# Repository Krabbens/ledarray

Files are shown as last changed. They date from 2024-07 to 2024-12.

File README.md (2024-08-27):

# Kolorowy wyświetlacz widmowy

## Spis Treści

- [Aplikacja](#flutter)
- [ESP PlatformIO](#esp-platformio)
- [PCB](#pcb)
- [Blender](#blender)
- [Przetwarzanie wstępne](#przetwarzanie-wstępne)

## Aplikacja do kontroli

1. Zainstaluj Flutter:

    - Pobierz Flutter SDK z https://flutter.dev/docs/get-started/install
    - Dodaj Flutter bin do PATH

2. Sprawdź instalację:

    ```bash
    flutter doctor
    ```

3. Uruchom projekt:

    ```bash
    cd /ścieżka/do/projektu
    flutter run
    ```

## ESP PlatformIO

1. Zainstaluj PlatformIO:

    - Pobierz PlatformIO IDE z https://platformio.org/install/ide?install=vscode

2. Skopiuj pliki z folderu esp/core_lib do odpowiadających folderów bibliotek espressif32 w domyślnej lokalizacji platformio

3. Uruchom projekt:

    - Otwórz PlatformIO IDE, załaduj projekt, użyj opcji "Build" i "Upload"

## PCB

1. Zainstaluj KiCad:

    - Pobierz KiCad z https://kicad.org/download/

2. Otwórz projekt:

    - Załaduj istniejący plik PCB w KiCad

## Blender

1. Zainstaluj Blender:

    - Pobierz Blender z https://www.blender.org/download/

2. Otwórz projekt:

    - Plik `cude.blend` jest głównym plikiem do renderowania animacji.
    - Plik `simul.blend` służy do symulacji animacji.

## Przetwarzanie wstępne

Zestaw skryptów służący do przetwarzania danych z blendera na format rozumiany przez program kontrolujący diody LED.

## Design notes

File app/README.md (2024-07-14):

# conn_app

A new Flutter project.

## Getting Started

This project is a starting point for a Flutter application.

A few resources to get you started if this is your first Flutter project:

- [Lab: Write your first Flutter app](https://docs.flutter.dev/get-started/codelab)
- [Cookbook: Useful Flutter samples](https://docs.flutter.dev/cookbook)

For help getting started with Flutter development, view the
[online documentation](https://docs.flutter.dev/), which offers tutorials,
samples, guidance on mobile development, and a full API reference.

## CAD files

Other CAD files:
3d/dysk v3.f3d
3d/kat 2 v1.f3d
3d/podstawa v2.f3d
3d/silnik góra v2.f3d
3d/silnik góra v3.f3d
3d/silnik v1 v2.f3d
3d/silnik v1 v3.f3d
3d/stopka trzymacza v2.f3d
3d/stopka trzymacza v3.f3d
3d/trzymacz v1.f3d
blender/atom.blend
blender/cube.blend

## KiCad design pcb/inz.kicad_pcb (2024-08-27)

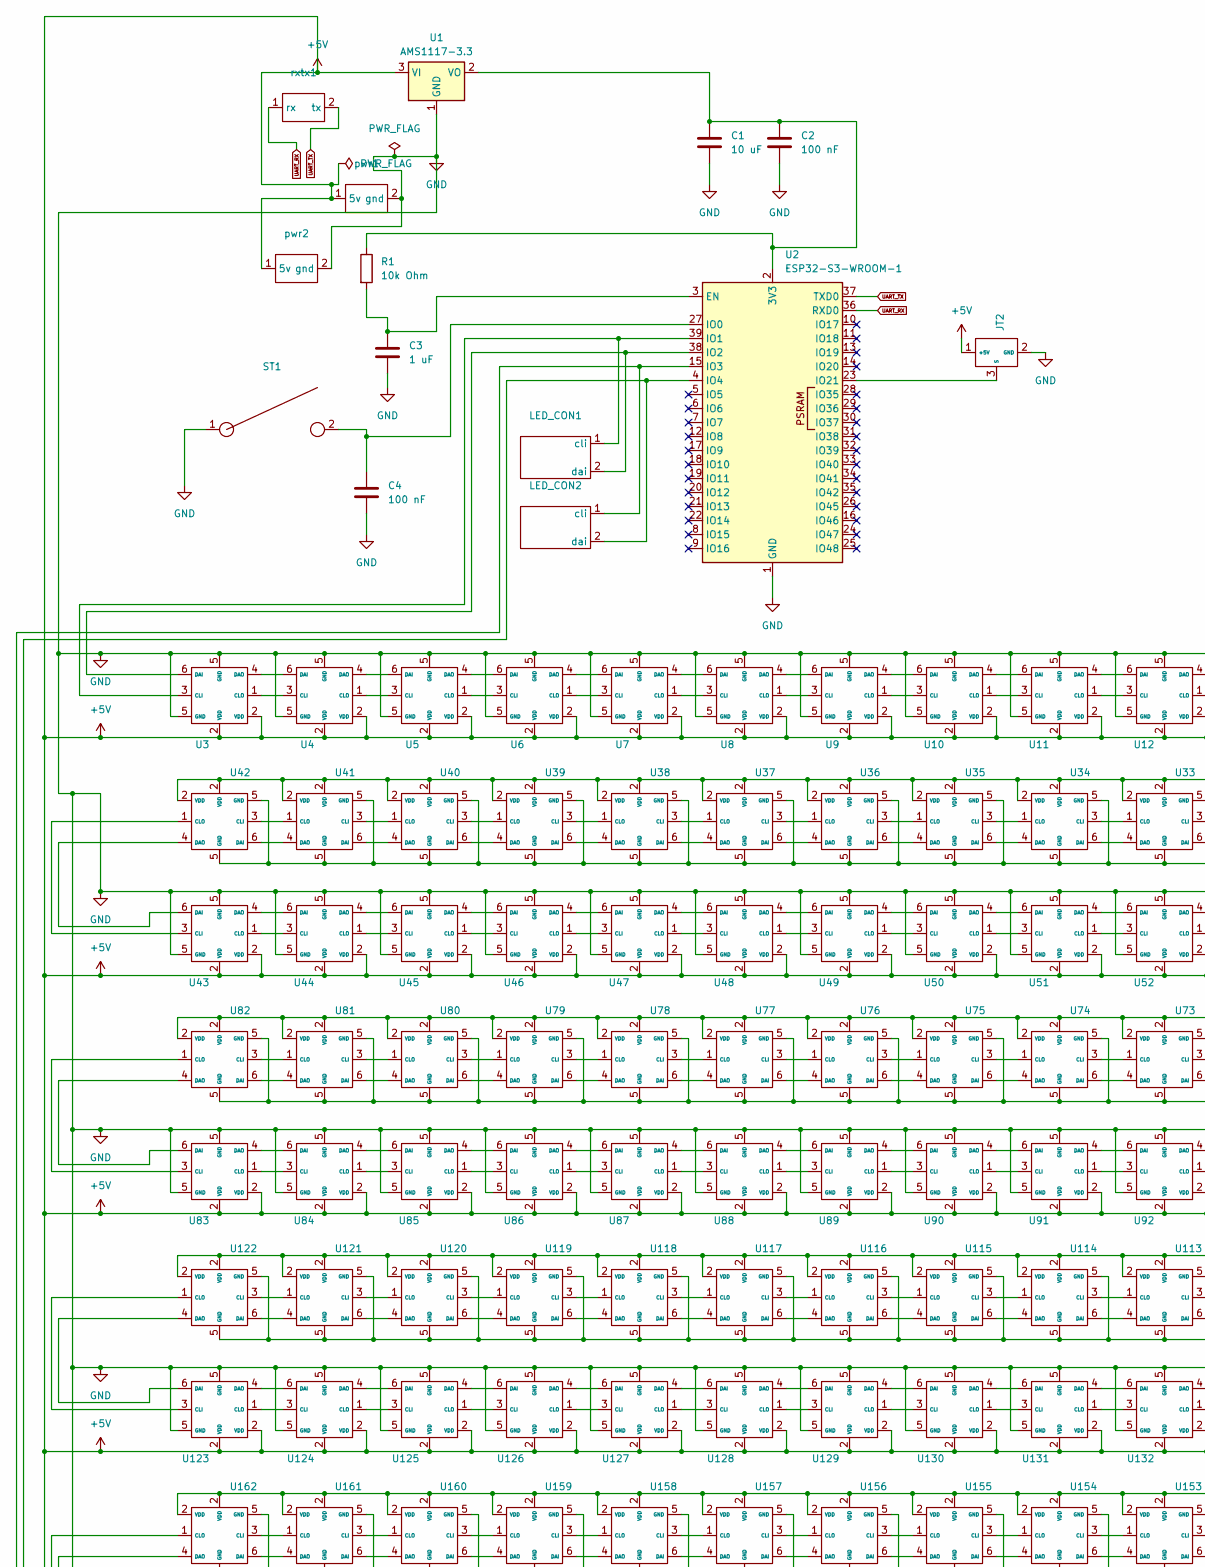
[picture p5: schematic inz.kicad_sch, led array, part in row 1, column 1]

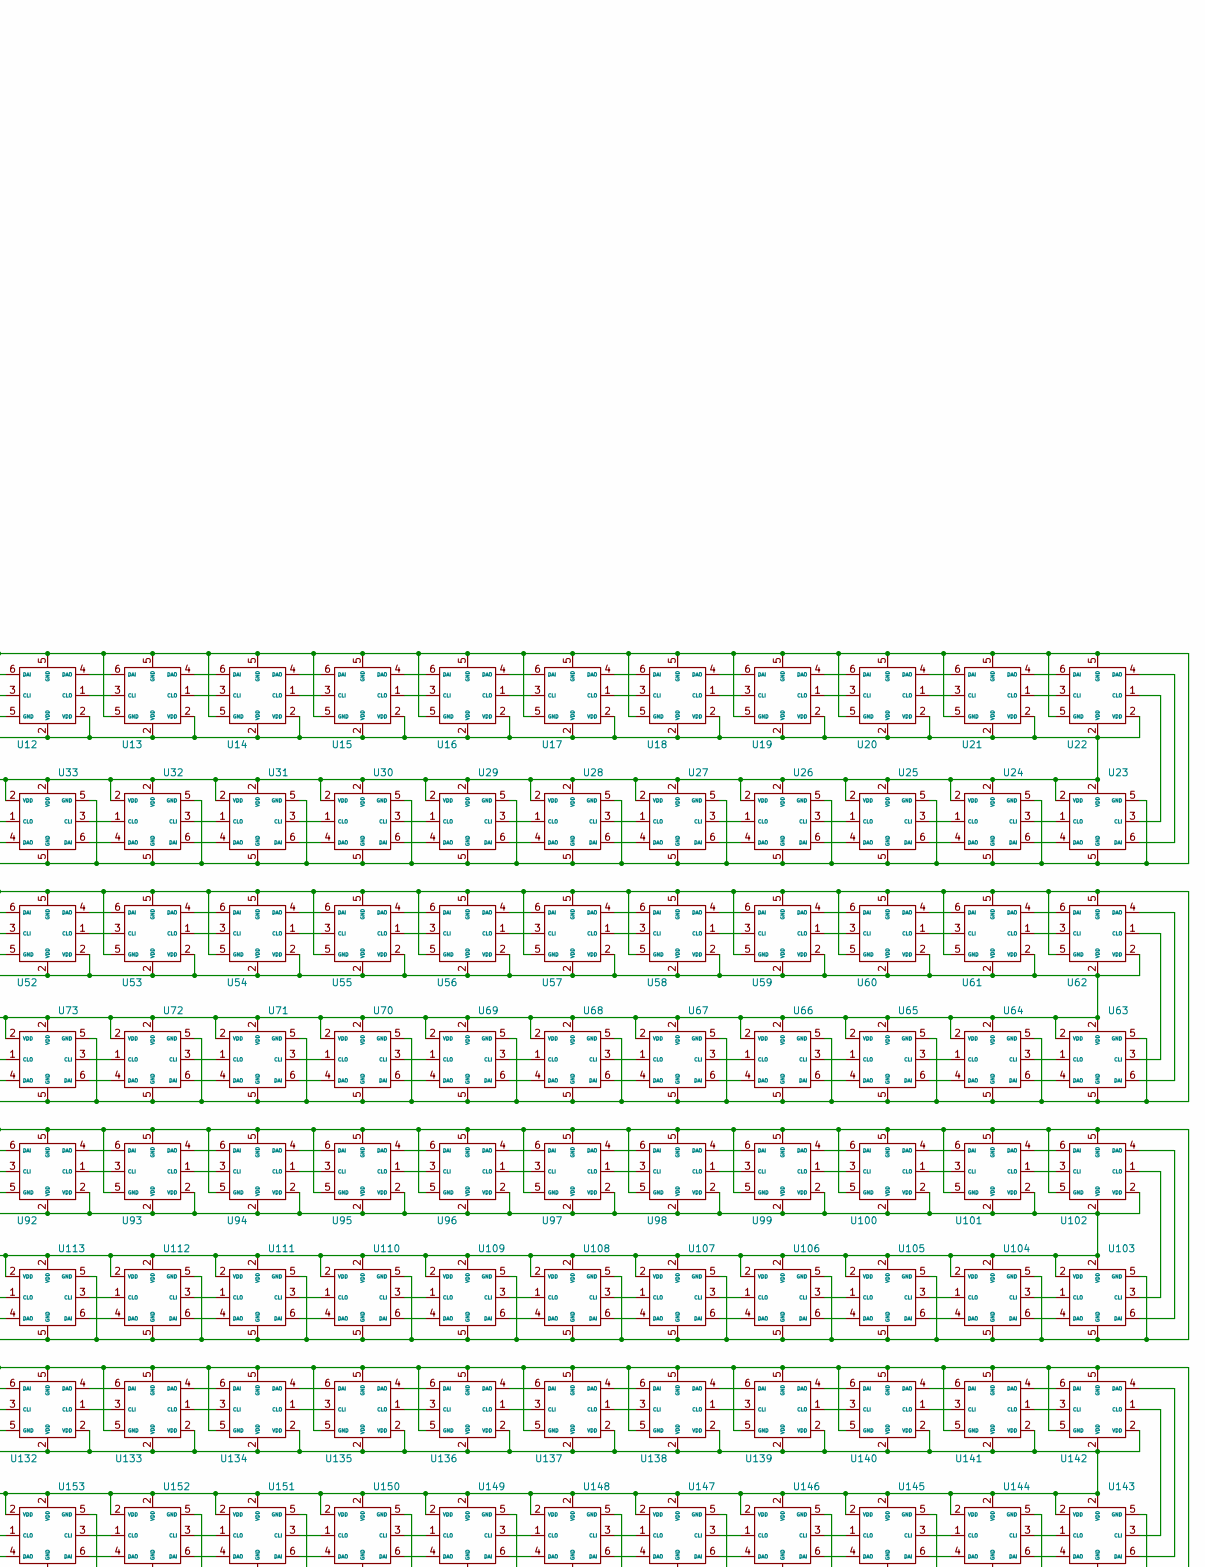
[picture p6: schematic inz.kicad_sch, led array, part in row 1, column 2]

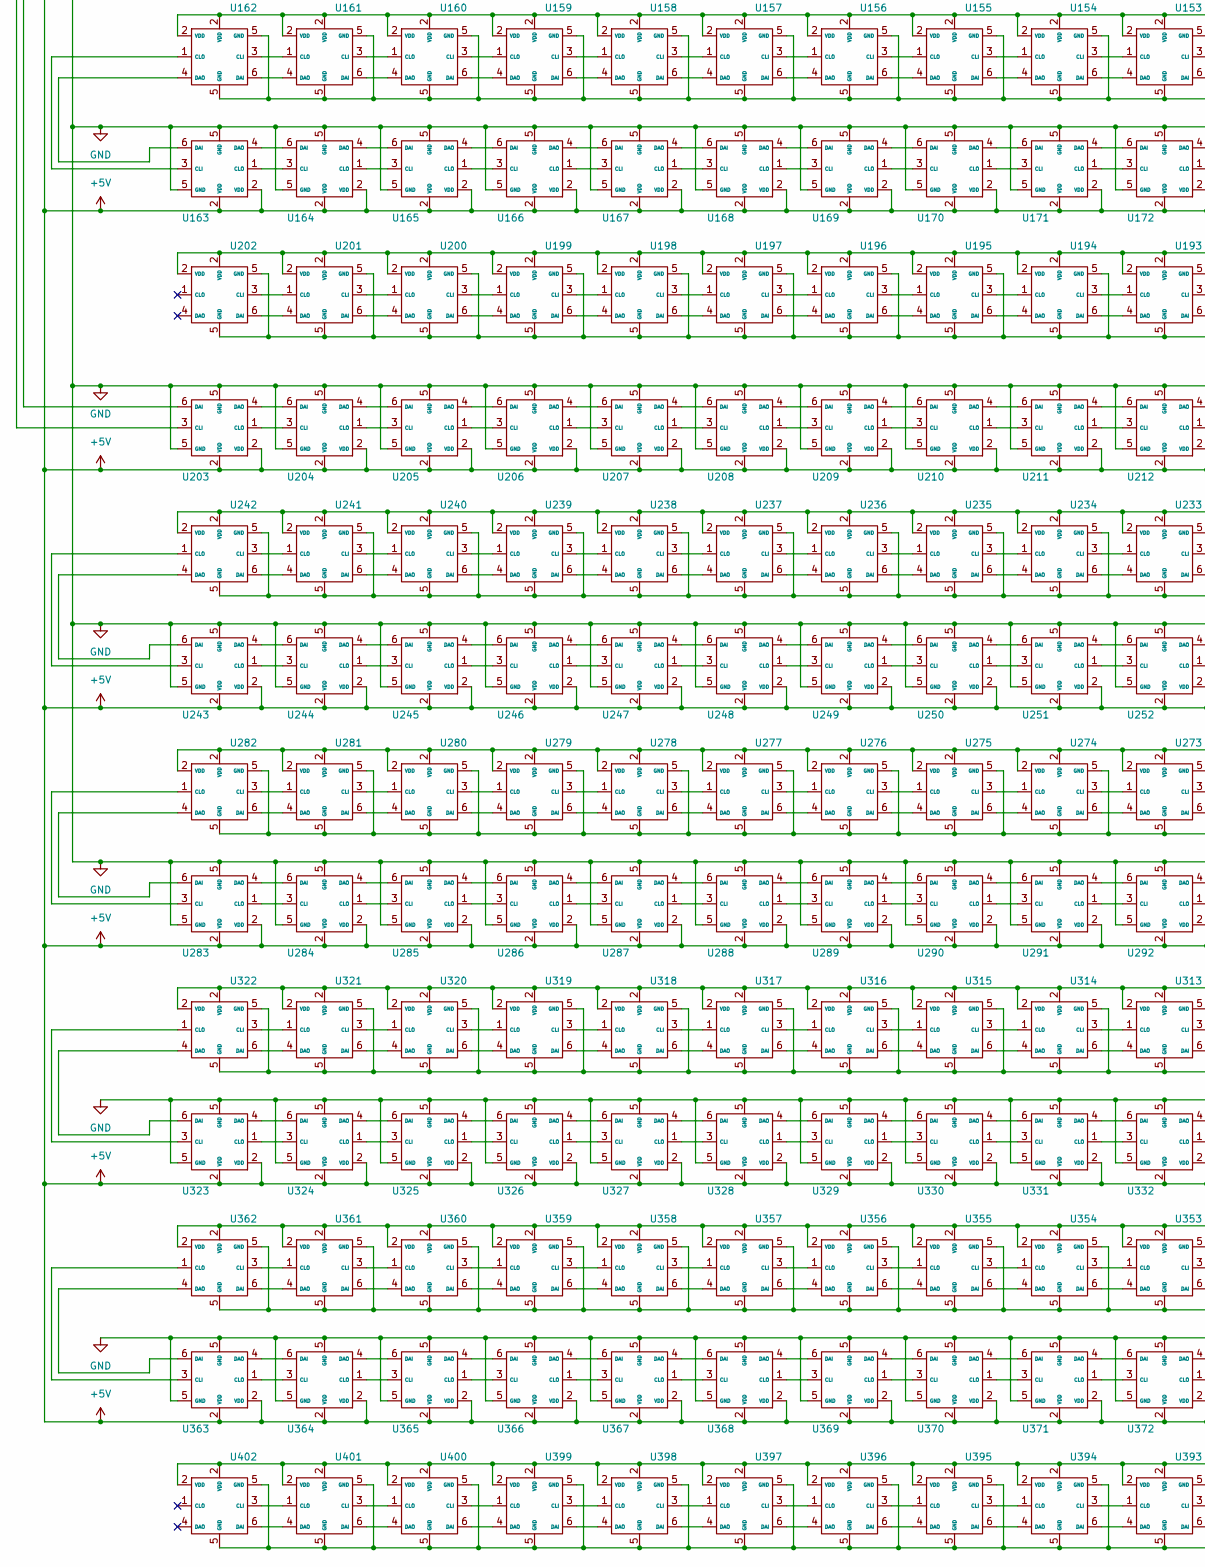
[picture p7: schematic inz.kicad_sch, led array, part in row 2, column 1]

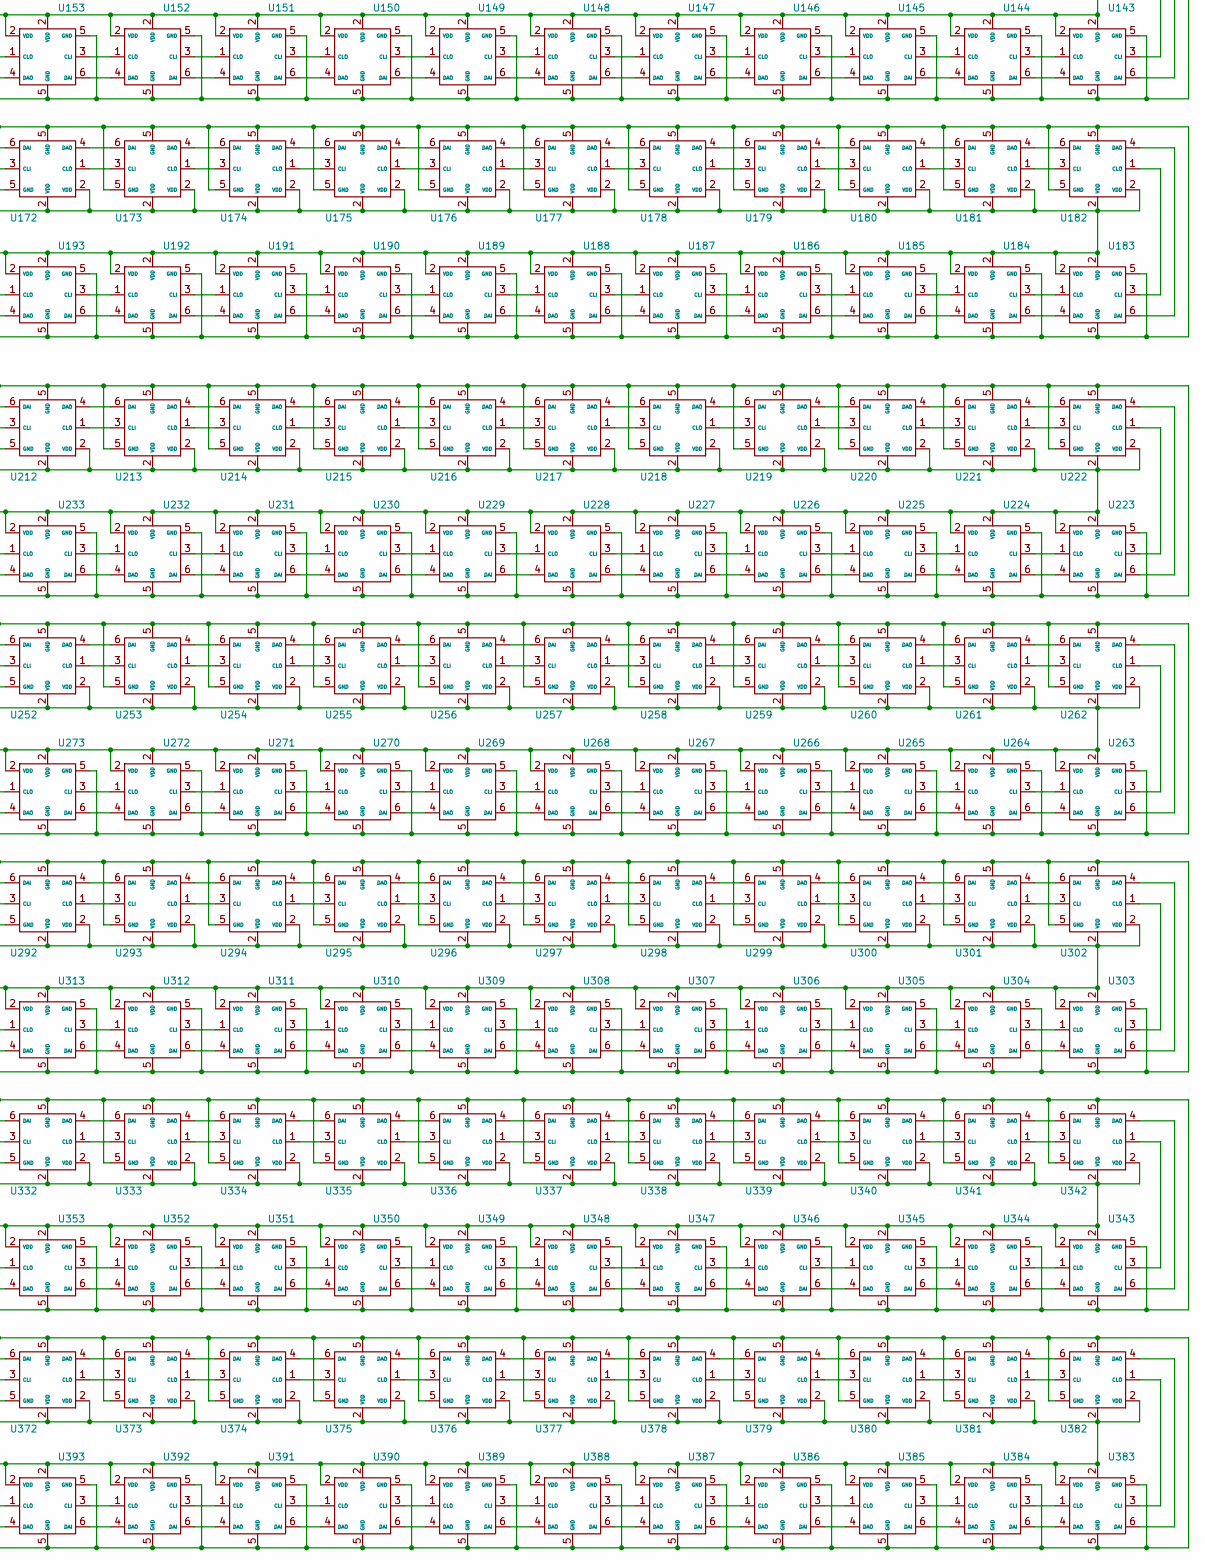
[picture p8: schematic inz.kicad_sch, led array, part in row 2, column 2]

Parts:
C1: 10 uF; C_0603_1608Metric
C2, C4: 100 nF; C_0402_1005Metric
C3: 1 uF; C_0402_1005Metric
JT2: hall JT
LED_CON1, LED_CON2: led_con
R1: 10k Ohm; R_0402_1005Metric
ST1: ST-1185S
U1: AMS1117-3.3; SOT-223-3_TabPin2
U2: ESP32-S3-WROOM-1
U3, U4, U5, U6, U7, U8, U9, U10, U11, U12, U13, U14, U15, U16, U17, U18, U19, U20, U21, U22, U23, U24, U25, U26, U27, U28, U29, U30, U31, U32, U33, U34, U35, U36, U37, U38, U39, U40, U41, U42, U43, U44, U45, U46, U47, U48, U49, U50, U51, U52, U53, U54, U55, U56, U57, U58, U59, U60, U61, U62, U63, U64, U65, U66, U67, U68, U69, U70, U71, U72, U73, U74, U75, U76, U77, U78, U79, U80, U81, U82, U83, U84, U85, U86, U87, U88, U89, U90, U91, U92, U93, U94, U95, U96, U97, U98, U99, U100, U101, U102, U103, U104, U105, U106, U107, U108, U109, U110, U111, U112, U113, U114, U115, U116, U117, U118, U119, U120, U121, U122, U123, U124, U125, U126, U127, U128, U129, U130, U131, U132, U133, U134, U135, U136, U137, U138, U139, U140, U141, U142, U143, U144, U145, U146, U147, U148, U149, U150, U151, U152, U153, U154, U155, U156, U157, U158, U159, U160, U161, U162, U163, U164, U165, U166, U167, U168, U169, U170, U171, U172, U173, U174, U175, U176, U177, U178, U179, U180, U181, U182, U183, U184, U185, U186, U187, U188, U189, U190, U191, U192, U193, U194, U195, U196, U197, U198, U199, U200, U201, U202, U203, U204, U205, U206, U207, U208, U209, U210, U211, U212, U213, U214, U215, U216, U217, U218, U219, U220, U221, U222, U223, U224, U225, U226, U227, U228, U229, U230, U231, U232, U233, U234, U235, U236, U237, U238, U239, U240, U241, U242, U243, U244, U245, U246, U247, U248, U249, U250, U251, U252, U253, U254, U255, U256, U257, U258, U259, U260, U261, U262, U263, U264, U265, U266, U267, U268, U269, U270, U271, U272, U273, U274, U275, U276, U277, U278, U279, U280, U281, U282, U283, U284, U285, U286, U287, U288, U289, U290, U291, U292, U293, U294, U295, U296, U297, U298, U299, U300, U301, U302, U303, U304, U305, U306, U307, U308, U309, U310, U311, U312, U313, U314, U315, U316, U317, U318, U319, U320, U321, U322, U323, U324, U325, U326, U327, U328, U329, U330, U331, U332, U333, U334, U335, U336, U337, U338, U339, U340, U341, U342, U343, U344, U345, U346, U347, U348, U349, U350, U351, U352, U353, U354, U355, U356, U357, U358, U359, U360, U361, U362, U363, U364, U365, U366, U367, U368, U369, U370, U371, U372, U373, U374, U375, U376, U377, U378, U379, U380, U381, U382, U383, U384, U385, U386, U387, U388, U389, U390, U391, U392, U393, U394, U395, U396, U397, U398, U399, U400, U401, U402: APA102-2020-6A
pwr1, pwr2: 5vgnd
rxtx1: rxtx

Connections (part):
+5V: JT2.1 (+5V), U1.3 (VI), U3.2 (VDD), U4.2 (VDD), U5.2 (VDD), U6.2 (VDD), U7.2 (VDD), U8.2 (VDD), U9.2 (VDD), U10.2 (VDD), U11.2 (VDD), U12.2 (VDD), U13.2 (VDD), U14.2 (VDD), U15.2 (VDD), U16.2 (VDD), U17.2 (VDD), U18.2 (VDD), U19.2 (VDD), U20.2 (VDD), U21.2 (VDD), U22.2 (VDD), U23.2 (VDD), U24.2 (VDD), U25.2 (VDD), U26.2 (VDD), U27.2 (VDD), U28.2 (VDD), U29.2 (VDD), U30.2 (VDD), U31.2 (VDD), U32.2 (VDD), U33.2 (VDD), U34.2 (VDD), U35.2 (VDD), U36.2 (VDD), U37.2 (VDD), U38.2 (VDD), U39.2 (VDD), U40.2 (VDD), U41.2 (VDD), U42.2 (VDD), U43.2 (VDD), U44.2 (VDD), U45.2 (VDD), U46.2 (VDD), U47.2 (VDD), U48.2 (VDD), U49.2 (VDD), U50.2 (VDD), U51.2 (VDD), U52.2 (VDD), U53.2 (VDD), U54.2 (VDD), U55.2 (VDD), U56.2 (VDD), U57.2 (VDD), U58.2 (VDD), U59.2 (VDD), U60.2 (VDD), U61.2 (VDD), U62.2 (VDD), U63.2 (VDD), U64.2 (VDD), U65.2 (VDD), U66.2 (VDD), U67.2 (VDD), U68.2 (VDD), U69.2 (VDD), U70.2 (VDD), U71.2 (VDD), U72.2 (VDD), U73.2 (VDD), U74.2 (VDD), U75.2 (VDD), U76.2 (VDD), U77.2 (VDD), U78.2 (VDD), U79.2 (VDD), U80.2 (VDD)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
GND: C1.2, C2.2, C3.2, C4.2, JT2.2 (GND), ST1.1, U1.1 (GND), U2.1 (GND), U2.40 (GND), U2.41 (GND), U3.5 (GND), U4.5 (GND), U5.5 (GND), U6.5 (GND), U7.5 (GND), U8.5 (GND), U9.5 (GND), U10.5 (GND), U11.5 (GND), U12.5 (GND), U13.5 (GND), U14.5 (GND), U15.5 (GND), U16.5 (GND), U17.5 (GND), U18.5 (GND), U19.5 (GND), U20.5 (GND), U21.5 (GND), U22.5 (GND), U23.5 (GND), U24.5 (GND), U25.5 (GND), U26.5 (GND), U27.5 (GND), U28.5 (GND), U29.5 (GND), U30.5 (GND), U31.5 (GND), U32.5 (GND), U33.5 (GND), U34.5 (GND), U35.5 (GND), U36.5 (GND), U37.5 (GND), U38.5 (GND), U39.5 (GND), U40.5 (GND), U41.5 (GND), U42.5 (GND), U43.5 (GND), U44.5 (GND), U45.5 (GND), U46.5 (GND), U47.5 (GND), U48.5 (GND), U49.5 (GND), U50.5 (GND), U51.5 (GND), U52.5 (GND), U53.5 (GND), U54.5 (GND), U55.5 (GND), U56.5 (GND), U57.5 (GND), U58.5 (GND), U59.5 (GND), U60.5 (GND), U61.5 (GND), U62.5 (GND), U63.5 (GND), U64.5 (GND), U65.5 (GND), U66.5 (GND), U67.5 (GND), U68.5 (GND), U69.5 (GND), U70.5 (GND), U71.5 (GND), U72.5 (GND)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
unnamed: JT2.3 (S), U2.23 (IO21)
unnamed: LED_CON1.1 (cli), U2.39 (IO1), U3.3 (CLI)
unnamed: LED_CON1.2 (dai), U2.38 (IO2), U3.6 (DAI)
unnamed: LED_CON2.1 (cli), U2.15 (IO3), U203.3 (CLI)
unnamed: LED_CON2.2 (dai), U2.4 (IO4), U203.6 (DAI)
unnamed: C1.1, C2.1, R1.1, U1.2 (VO), U2.2 (3V3)
unnamed: C3.1, R1.2, U2.3 (EN)
unnamed: C4.1, ST1.2, U2.27 (IO0)
unnamed: U3.1 (CLO), U4.3 (CLI)
unnamed: U3.4 (DAO), U4.6 (DAI)
unnamed: U4.1 (CLO), U5.3 (CLI)
unnamed: U4.4 (DAO), U5.6 (DAI)
unnamed: U5.1 (CLO), U6.3 (CLI)
unnamed: U5.4 (DAO), U6.6 (DAI)
unnamed: U6.1 (CLO), U7.3 (CLI)
unnamed: U6.4 (DAO), U7.6 (DAI)
unnamed: U7.1 (CLO), U8.3 (CLI)
unnamed: U7.4 (DAO), U8.6 (DAI)
unnamed: U8.1 (CLO), U9.3 (CLI)
unnamed: U8.4 (DAO), U9.6 (DAI)
unnamed: U9.1 (CLO), U10.3 (CLI)
unnamed: U10.1 (CLO), U11.3 (CLI)
unnamed: U9.4 (DAO), U10.6 (DAI)
unnamed: U10.4 (DAO), U11.6 (DAI)
unnamed: U11.1 (CLO), U12.3 (CLI)
unnamed: U11.4 (DAO), U12.6 (DAI)
unnamed: U12.1 (CLO), U13.3 (CLI)
unnamed: U12.4 (DAO), U13.6 (DAI)
unnamed: U13.1 (CLO), U14.3 (CLI)
unnamed: U13.4 (DAO), U14.6 (DAI)
unnamed: U14.1 (CLO), U15.3 (CLI)
unnamed: U14.4 (DAO), U15.6 (DAI)
unnamed: U15.1 (CLO), U16.3 (CLI)
unnamed: U15.4 (DAO), U16.6 (DAI)
unnamed: U16.1 (CLO), U17.3 (CLI)
unnamed: U16.4 (DAO), U17.6 (DAI)
unnamed: U17.1 (CLO), U18.3 (CLI)
unnamed: U17.4 (DAO), U18.6 (DAI)
unnamed: U18.1 (CLO), U19.3 (CLI)
unnamed: U18.4 (DAO), U19.6 (DAI)
unnamed: U19.1 (CLO), U20.3 (CLI)
unnamed: U19.4 (DAO), U20.6 (DAI)
unnamed: U20.1 (CLO), U21.3 (CLI)
unnamed: U20.4 (DAO), U21.6 (DAI)
unnamed: U21.1 (CLO), U22.3 (CLI)
unnamed: U21.4 (DAO), U22.6 (DAI)
unnamed: U22.1 (CLO), U23.3 (CLI)
unnamed: U22.4 (DAO), U23.6 (DAI)
unnamed: U23.1 (CLO), U24.3 (CLI)
unnamed: U23.4 (DAO), U24.6 (DAI)
unnamed: U24.1 (CLO), U25.3 (CLI)
unnamed: U24.4 (DAO), U25.6 (DAI)
unnamed: U25.1 (CLO), U26.3 (CLI)
unnamed: U25.4 (DAO), U26.6 (DAI)
unnamed: U26.1 (CLO), U27.3 (CLI)
unnamed: U26.4 (DAO), U27.6 (DAI)
unnamed: U27.1 (CLO), U28.3 (CLI)
unnamed: U27.4 (DAO), U28.6 (DAI)
unnamed: U28.1 (CLO), U29.3 (CLI)
unnamed: U28.4 (DAO), U29.6 (DAI)
unnamed: U29.1 (CLO), U30.3 (CLI)
unnamed: U29.4 (DAO), U30.6 (DAI)
unnamed: U30.1 (CLO), U31.3 (CLI)
unnamed: U30.4 (DAO), U31.6 (DAI)
unnamed: U31.1 (CLO), U32.3 (CLI)
unnamed: U31.4 (DAO), U32.6 (DAI)
unnamed: U32.1 (CLO), U33.3 (CLI)
unnamed: U32.4 (DAO), U33.6 (DAI)
unnamed: U33.1 (CLO), U34.3 (CLI)
unnamed: U33.4 (DAO), U34.6 (DAI)
unnamed: U34.1 (CLO), U35.3 (CLI)
unnamed: U34.4 (DAO), U35.6 (DAI)
unnamed: U35.1 (CLO), U36.3 (CLI)
unnamed: U35.4 (DAO), U36.6 (DAI)
unnamed: U36.1 (CLO), U37.3 (CLI)
unnamed: U36.4 (DAO), U37.6 (DAI)
unnamed: U37.1 (CLO), U38.3 (CLI)
unnamed: U37.4 (DAO), U38.6 (DAI)
unnamed: U38.1 (CLO), U39.3 (CLI)
unnamed: U38.4 (DAO), U39.6 (DAI)
unnamed: U39.1 (CLO), U40.3 (CLI)
unnamed: U39.4 (DAO), U40.6 (DAI)
unnamed: U40.1 (CLO), U41.3 (CLI)
unnamed: U40.4 (DAO), U41.6 (DAI)
unnamed: U41.1 (CLO), U42.3 (CLI)
unnamed: U41.4 (DAO), U42.6 (DAI)
unnamed: U42.1 (CLO), U43.3 (CLI)
unnamed: U42.4 (DAO), U43.6 (DAI)
unnamed: U43.1 (CLO), U44.3 (CLI)
unnamed: U43.4 (DAO), U44.6 (DAI)
unnamed: U44.1 (CLO), U45.3 (CLI)
unnamed: U44.4 (DAO), U45.6 (DAI)
unnamed: U45.1 (CLO), U46.3 (CLI)
unnamed: U45.4 (DAO), U46.6 (DAI)
unnamed: U46.1 (CLO), U47.3 (CLI)
unnamed: U46.4 (DAO), U47.6 (DAI)
unnamed: U47.1 (CLO), U48.3 (CLI)
unnamed: U47.4 (DAO), U48.6 (DAI)
unnamed: U48.1 (CLO), U49.3 (CLI)
unnamed: U48.4 (DAO), U49.6 (DAI)
unnamed: U49.1 (CLO), U50.3 (CLI)
unnamed: U49.4 (DAO), U50.6 (DAI)
unnamed: U50.1 (CLO), U51.3 (CLI)
unnamed: U50.4 (DAO), U51.6 (DAI)
unnamed: U51.1 (CLO), U52.3 (CLI)
unnamed: U51.4 (DAO), U52.6 (DAI)
unnamed: U52.1 (CLO), U53.3 (CLI)
unnamed: U52.4 (DAO), U53.6 (DAI)
unnamed: U53.1 (CLO), U54.3 (CLI)
unnamed: U53.4 (DAO), U54.6 (DAI)
unnamed: U54.1 (CLO), U55.3 (CLI)
unnamed: U54.4 (DAO), U55.6 (DAI)
unnamed: U55.1 (CLO), U56.3 (CLI)
unnamed: U55.4 (DAO), U56.6 (DAI)
unnamed: U56.1 (CLO), U57.3 (CLI)
unnamed: U56.4 (DAO), U57.6 (DAI)
unnamed: U57.1 (CLO), U58.3 (CLI)
unnamed: U57.4 (DAO), U58.6 (DAI)
unnamed: U58.1 (CLO), U59.3 (CLI)
unnamed: U58.4 (DAO), U59.6 (DAI)
unnamed: U59.1 (CLO), U60.3 (CLI)
unnamed: U59.4 (DAO), U60.6 (DAI)
unnamed: U60.1 (CLO), U61.3 (CLI)
unnamed: U60.4 (DAO), U61.6 (DAI)
unnamed: U61.1 (CLO), U62.3 (CLI)
unnamed: U61.4 (DAO), U62.6 (DAI)
unnamed: U62.1 (CLO), U63.3 (CLI)
unnamed: U62.4 (DAO), U63.6 (DAI)
unnamed: U63.1 (CLO), U64.3 (CLI)
unnamed: U63.4 (DAO), U64.6 (DAI)
unnamed: U64.1 (CLO), U65.3 (CLI)
unnamed: U64.4 (DAO), U65.6 (DAI)
unnamed: U65.1 (CLO), U66.3 (CLI)
unnamed: U65.4 (DAO), U66.6 (DAI)
unnamed: U66.1 (CLO), U67.3 (CLI)
unnamed: U66.4 (DAO), U67.6 (DAI)
unnamed: U67.1 (CLO), U68.3 (CLI)
unnamed: U67.4 (DAO), U68.6 (DAI)
unnamed: U68.1 (CLO), U69.3 (CLI)
unnamed: U68.4 (DAO), U69.6 (DAI)
unnamed: U69.1 (CLO), U70.3 (CLI)
unnamed: U69.4 (DAO), U70.6 (DAI)
unnamed: U70.1 (CLO), U71.3 (CLI)
unnamed: U70.4 (DAO), U71.6 (DAI)
unnamed: U71.1 (CLO), U72.3 (CLI)
unnamed: U71.4 (DAO), U72.6 (DAI)
unnamed: U72.1 (CLO), U73.3 (CLI)
unnamed: U72.4 (DAO), U73.6 (DAI)
unnamed: U73.1 (CLO), U74.3 (CLI)
unnamed: U73.4 (DAO), U74.6 (DAI)
unnamed: U74.1 (CLO), U75.3 (CLI)
unnamed: U74.4 (DAO), U75.6 (DAI)
unnamed: U75.1 (CLO), U76.3 (CLI)
unnamed: U75.4 (DAO), U76.6 (DAI)
unnamed: U76.1 (CLO), U77.3 (CLI)
unnamed: U76.4 (DAO), U77.6 (DAI)
unnamed: U77.1 (CLO), U78.3 (CLI)
unnamed: U77.4 (DAO), U78.6 (DAI)
unnamed: U78.1 (CLO), U79.3 (CLI)
unnamed: U78.4 (DAO), U79.6 (DAI)
unnamed: U79.1 (CLO), U80.3 (CLI)
unnamed: U79.4 (DAO), U80.6 (DAI)
unnamed: U80.1 (CLO), U81.3 (CLI)
unnamed: U80.4 (DAO), U81.6 (DAI)
unnamed: U81.1 (CLO), U82.3 (CLI)
unnamed: U81.4 (DAO), U82.6 (DAI)
unnamed: U82.1 (CLO), U83.3 (CLI)
unnamed: U82.4 (DAO), U83.6 (DAI)
unnamed: U83.1 (CLO), U84.3 (CLI)
unnamed: U83.4 (DAO), U84.6 (DAI)
unnamed: U84.1 (CLO), U85.3 (CLI)
unnamed: U84.4 (DAO), U85.6 (DAI)
unnamed: U85.1 (CLO), U86.3 (CLI)
unnamed: U85.4 (DAO), U86.6 (DAI)
unnamed: U86.1 (CLO), U87.3 (CLI)
unnamed: U86.4 (DAO), U87.6 (DAI)
unnamed: U87.1 (CLO), U88.3 (CLI)
unnamed: U87.4 (DAO), U88.6 (DAI)
unnamed: U88.1 (CLO), U89.3 (CLI)
unnamed: U88.4 (DAO), U89.6 (DAI)
unnamed: U89.1 (CLO), U90.3 (CLI)
unnamed: U89.4 (DAO), U90.6 (DAI)
unnamed: U90.1 (CLO), U91.3 (CLI)
unnamed: U90.4 (DAO), U91.6 (DAI)
unnamed: U91.1 (CLO), U92.3 (CLI)
unnamed: U91.4 (DAO), U92.6 (DAI)
unnamed: U92.1 (CLO), U93.3 (CLI)
unnamed: U92.4 (DAO), U93.6 (DAI)
unnamed: U93.1 (CLO), U94.3 (CLI)
unnamed: U93.4 (DAO), U94.6 (DAI)
unnamed: U94.1 (CLO), U95.3 (CLI)
unnamed: U94.4 (DAO), U95.6 (DAI)
unnamed: U95.1 (CLO), U96.3 (CLI)
unnamed: U95.4 (DAO), U96.6 (DAI)
unnamed: U96.1 (CLO), U97.3 (CLI)
unnamed: U96.4 (DAO), U97.6 (DAI)
unnamed: U97.1 (CLO), U98.3 (CLI)
unnamed: U97.4 (DAO), U98.6 (DAI)
unnamed: U98.1 (CLO), U99.3 (CLI)
unnamed: U98.4 (DAO), U99.6 (DAI)
unnamed: U99.1 (CLO), U100.3 (CLI)
unnamed: U100.1 (CLO), U101.3 (CLI)
unnamed: U99.4 (DAO), U100.6 (DAI)
unnamed: U100.4 (DAO), U101.6 (DAI)
unnamed: U101.1 (CLO), U102.3 (CLI)
unnamed: U101.4 (DAO), U102.6 (DAI)
unnamed: U102.1 (CLO), U103.3 (CLI)
unnamed: U102.4 (DAO), U103.6 (DAI)
unnamed: U103.1 (CLO), U104.3 (CLI)
unnamed: U103.4 (DAO), U104.6 (DAI)
unnamed: U104.1 (CLO), U105.3 (CLI)
unnamed: U104.4 (DAO), U105.6 (DAI)
unnamed: U105.1 (CLO), U106.3 (CLI)
unnamed: U105.4 (DAO), U106.6 (DAI)
unnamed: U106.1 (CLO), U107.3 (CLI)
unnamed: U106.4 (DAO), U107.6 (DAI)
unnamed: U107.1 (CLO), U108.3 (CLI)
unnamed: U107.4 (DAO), U108.6 (DAI)
unnamed: U108.1 (CLO), U109.3 (CLI)
unnamed: U108.4 (DAO), U109.6 (DAI)
unnamed: U109.1 (CLO), U110.3 (CLI)
unnamed: U109.4 (DAO), U110.6 (DAI)
unnamed: U110.1 (CLO), U111.3 (CLI)
unnamed: U110.4 (DAO), U111.6 (DAI)
unnamed: U111.1 (CLO), U112.3 (CLI)
unnamed: U111.4 (DAO), U112.6 (DAI)
unnamed: U112.1 (CLO), U113.3 (CLI)
unnamed: U112.4 (DAO), U113.6 (DAI)
unnamed: U113.1 (CLO), U114.3 (CLI)
unnamed: U113.4 (DAO), U114.6 (DAI)
unnamed: U114.1 (CLO), U115.3 (CLI)
unnamed: U114.4 (DAO), U115.6 (DAI)
unnamed: U115.1 (CLO), U116.3 (CLI)
unnamed: U115.4 (DAO), U116.6 (DAI)
unnamed: U116.1 (CLO), U117.3 (CLI)
unnamed: U116.4 (DAO), U117.6 (DAI)
unnamed: U117.1 (CLO), U118.3 (CLI)
unnamed: U117.4 (DAO), U118.6 (DAI)
unnamed: U118.1 (CLO), U119.3 (CLI)
unnamed: U118.4 (DAO), U119.6 (DAI)
unnamed: U119.1 (CLO), U120.3 (CLI)
unnamed: U119.4 (DAO), U120.6 (DAI)
unnamed: U120.1 (CLO), U121.3 (CLI)
unnamed: U120.4 (DAO), U121.6 (DAI)
unnamed: U121.1 (CLO), U122.3 (CLI)
unnamed: U121.4 (DAO), U122.6 (DAI)
unnamed: U122.1 (CLO), U123.3 (CLI)
unnamed: U122.4 (DAO), U123.6 (DAI)
unnamed: U123.1 (CLO), U124.3 (CLI)
unnamed: U123.4 (DAO), U124.6 (DAI)
unnamed: U124.1 (CLO), U125.3 (CLI)
unnamed: U124.4 (DAO), U125.6 (DAI)
unnamed: U125.1 (CLO), U126.3 (CLI)
unnamed: U125.4 (DAO), U126.6 (DAI)
unnamed: U126.1 (CLO), U127.3 (CLI)
unnamed: U126.4 (DAO), U127.6 (DAI)
unnamed: U127.1 (CLO), U128.3 (CLI)
unnamed: U127.4 (DAO), U128.6 (DAI)
unnamed: U128.1 (CLO), U129.3 (CLI)
unnamed: U128.4 (DAO), U129.6 (DAI)
unnamed: U129.1 (CLO), U130.3 (CLI)
unnamed: U129.4 (DAO), U130.6 (DAI)
unnamed: U130.1 (CLO), U131.3 (CLI)
unnamed: U130.4 (DAO), U131.6 (DAI)
unnamed: U131.1 (CLO), U132.3 (CLI)
unnamed: U131.4 (DAO), U132.6 (DAI)
unnamed: U132.1 (CLO), U133.3 (CLI)
unnamed: U132.4 (DAO), U133.6 (DAI)
unnamed: U133.1 (CLO), U134.3 (CLI)
unnamed: U133.4 (DAO), U134.6 (DAI)
unnamed: U134.1 (CLO), U135.3 (CLI)
unnamed: U134.4 (DAO), U135.6 (DAI)
unnamed: U135.1 (CLO), U136.3 (CLI)
unnamed: U135.4 (DAO), U136.6 (DAI)
unnamed: U136.1 (CLO), U137.3 (CLI)
unnamed: U136.4 (DAO), U137.6 (DAI)
unnamed: U137.1 (CLO), U138.3 (CLI)
unnamed: U137.4 (DAO), U138.6 (DAI)
unnamed: U138.1 (CLO), U139.3 (CLI)
unnamed: U138.4 (DAO), U139.6 (DAI)
unnamed: U139.1 (CLO), U140.3 (CLI)
unnamed: U139.4 (DAO), U140.6 (DAI)
unnamed: U140.1 (CLO), U141.3 (CLI)
unnamed: U140.4 (DAO), U141.6 (DAI)
unnamed: U141.1 (CLO), U142.3 (CLI)
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

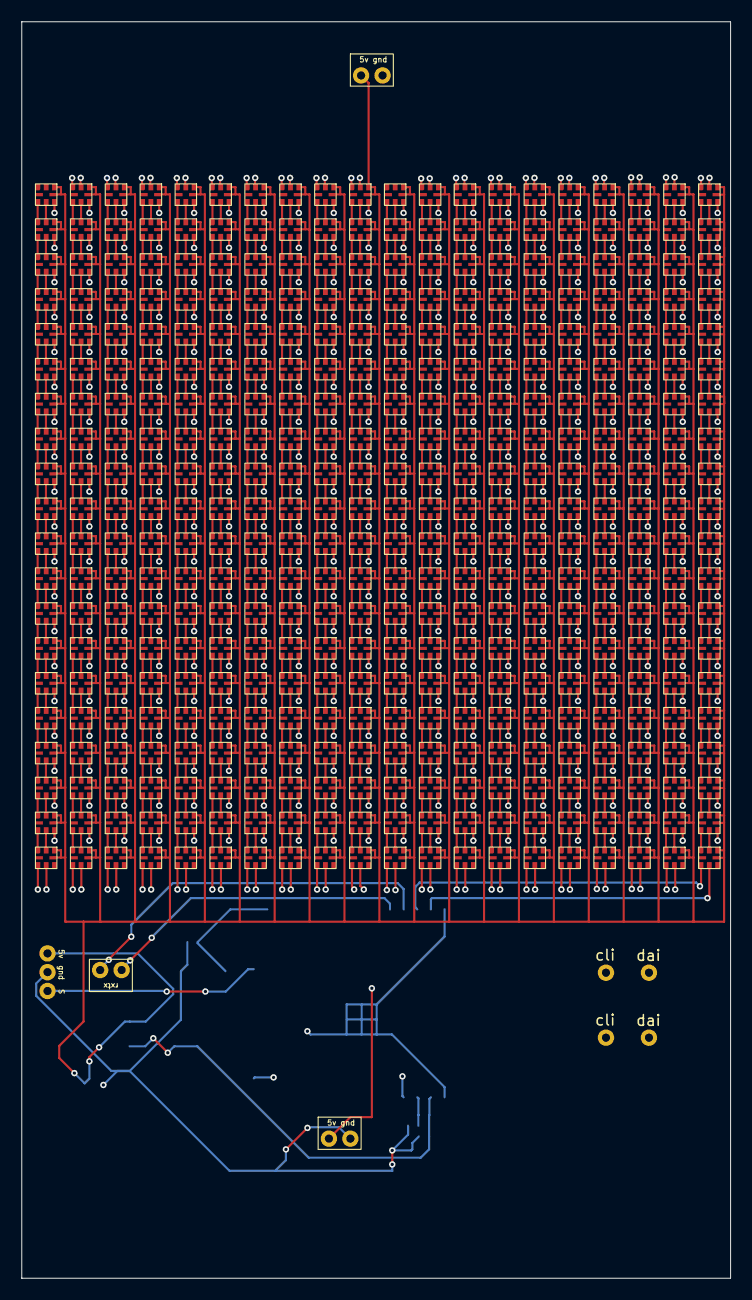
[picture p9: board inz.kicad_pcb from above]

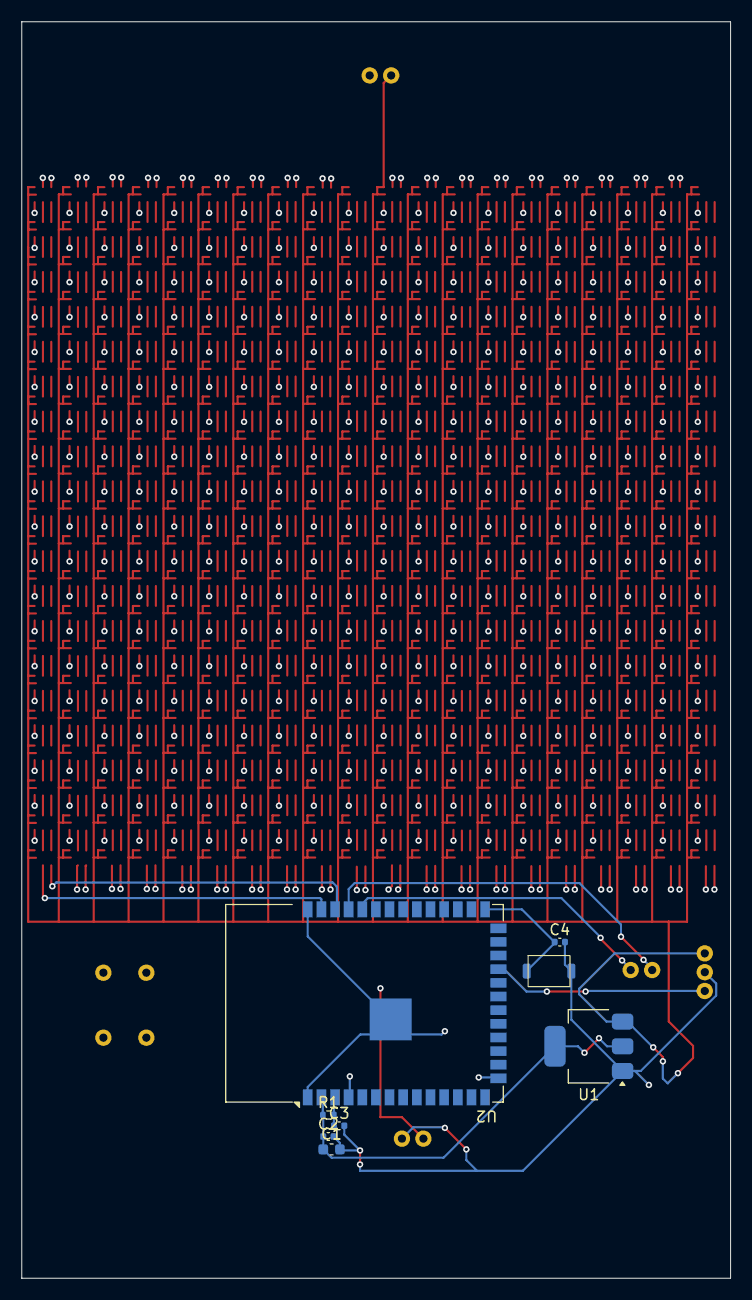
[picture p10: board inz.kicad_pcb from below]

Board: 4 copper layers, 66.0 x 117.0 mm, 414 parts (8 on the bottom side), 808 nets.

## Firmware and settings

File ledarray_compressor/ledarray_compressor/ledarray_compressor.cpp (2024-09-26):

#include <iostream>
#include <fstream>
#include <cstdlib>
#include <string>
#include <sstream>
#include <iomanip>
#include <vector>
#include "lz4.h"
#include "ColorCompressor.h"

#define FRAMES_ONE_SPIN 30
#define DEFAULT_BLOCK_SIZE 400; // one frame
#define EXTENSION ".lz4"
#define BMP_HEADER_SIZE 54

int BLOCK_SIZE = DEFAULT_BLOCK_SIZE;
bool debug = false;

std::vector<char> merge_bmp_files(const std::string& folder_path, int spins) {
    std::vector<char> merged_data;

    for (int j = 1; j <= spins; ++j) {
        for (int i = 0; i < FRAMES_ONE_SPIN; ++i) {
            std::ostringstream filename_stream;
            filename_stream << std::setw(3) << std::setfill('0') << j << "_"
                << std::setw(2) << std::setfill('0') << i << ".bmp";

            std::string subfolder_path = folder_path + "/" + std::to_string(i);
            std::string bmp_file_path = subfolder_path + "/" + filename_stream.str();
            std::ifstream bmp_file(bmp_file_path, std::ios::binary);
            if (bmp_file) {
                // skip bmp header
                bmp_file.seekg(BMP_HEADER_SIZE);
                std::vector<char> file_data((std::istreambuf_iterator<char>(bmp_file)), std::istreambuf_iterator<char>());
                merged_data.insert(merged_data.end(), file_data.begin(), file_data.end());
            }
            else {
                std::cout << "Cannot open input file: " << bmp_file_path << std::endl;
                exit(1);
            }
        }
    }

    if (debug) {
        int pixel_count = 0; 
        for (int i = 0; i < 20; ++i) {
            for (int j = 0; j < 20; ++j) {
                int index = (i * 20 + j) * 3; 
                if (index + 2 < merged_data.size()) {
                    unsigned char blue = static_cast<unsigned char>(merged_data[index]);
                    unsigned char green = static_cast<unsigned char>(merged_data[index + 1]);
                    unsigned char red = static_cast<unsigned char>(merged_data[index + 2]);
                    std::cout << "(" << std::setw(3) << (int)red << ", "
                        << std::setw(3) << (int)green << ", "
                        << std::setw(3) << (int)blue << ") ";
                }
                else {
                    std::cout << "(---, ---, ---) ";
                }
                pixel_count++;
            }
            std::cout << std::endl;
        }
    }

    return merged_data;
}

std::vector<char> rotate(std::vector<char> vec) {
    const int block_size = 20;
    const int frame_size = block_size * block_size;

    std::vector<char> rotated(vec.size());

    for (int frame_i = 0; frame_i * frame_size < vec.size(); frame_i++) {
        int frame_n = frame_i * frame_size;

        for (int row_i = 0; row_i < block_size; row_i++) {
            for (int column_i = 0; column_i < block_size; column_i++) {
                // Calculate rotated positions
                int new_row = block_size - 1 - column_i;  // Flip the row to correct the upside-down issue
                int new_column = row_i;

                // Map the original index to the rotated index
                rotated[frame_n + new_row * block_size + new_column] = vec[frame_n + row_i * block_size + column_i];
            }
        }
    }

    return rotated;
}

void lz4Compress(const char* input, std::ofstream& outputFile) {

    char* compressed = new char[LZ4_compressBound(BLOCK_SIZE)];
    if (!compressed) {
        std::cout << "Memory allocation error" << std::endl;
        return;
    }

    short compressedSize = LZ4_compress_default(input, compressed, BLOCK_SIZE, LZ4_compressBound(BLOCK_SIZE));

    if (debug) {
        static int blockNum = 0; static int totalSize = 0; totalSize += compressedSize;
        std::cout << "[ " << blockNum++ << " ] " << "Compressed size: " << compressedSize << "\tTotal size: " << totalSize << std::endl;
    }

    if (compressedSize <= 0) {
        std::cout << "Compression error" << std::endl;
        delete[] compressed;
        return;
    }

    uint16_t size = static_cast<uint16_t>(compressedSize);
    outputFile.write(reinterpret_cast<const char*>(&size), sizeof(size));
    outputFile.write(compressed, compressedSize);
    if (debug) std::cout << "Current pos: " << outputFile.tellp() << std::endl;
    delete[] compressed;
}

void compressFile(const char* inputFilename, const char* outputFilename, int spins) {

    std::cout << "Merging files..." << std::endl;
    std::vector<char> inputVec = merge_bmp_files(inputFilename, spins);

    if (debug) {
        std::ofstream mergedFile(std::string(outputFilename) + "_merged_data.raw", std::ios::binary);
        if (!mergedFile) {
            std::cout << "Cannot open merged file for writing." << std::endl;
            exit(1);
        }
        mergedFile.write(inputVec.data(), inputVec.size());
        mergedFile.close();
    }

    std::cout << "Compressing... 1/2" << std::endl;
    std::vector<char> colorsVec = ColorCompressor::convertColorsToIndices(inputVec);
    inputVec.clear();

    if (debug) {
        std::ofstream colorCompressedFile(std::string(outputFilename) + "_color_compressed.raw", std::ios::binary);
        if (!colorCompressedFile) {
            std::cout << "Cannot open color-compressed file for writing." << std::endl;
            exit(1);
        }
        colorCompressedFile.write(colorsVec.data(), colorsVec.size());
        colorCompressedFile.close();
    }

    std::cout << "Rotating... " << std::endl;
    std::vector<char> rotated = rotate(colorsVec);
    colorsVec.clear();

    size_t totalBytes = rotated.size();
    char* input = rotated.data();
    size_t offset = 0;

    std::ofstream outputFile(outputFilename, std::ios::binary);
    if (!outputFile) {
        std::cout << "Cannot open output file" << std::endl;
        exit(1);
    }

    std::cout << "Compressing... 2/2" << std::endl;

    while (offset + BLOCK_SIZE <= totalBytes) {
        lz4Compress(input + offset, outputFile);
        offset += BLOCK_SIZE;
    }

    if (offset != totalBytes) {
        std::cout << "Error: Not all data has been processed. Please check if the block size is appropriate." << std::endl;
        exit(1);
    }

    if (debug) std::cout << "Final pos: " << outputFile.tellp() << std::endl;
    outputFile.close();

}

std::string changeExtension(const std::string& filename, const std::string& newExt) {
    size_t dotPosition = filename.find_last_of('.');
    if (dotPosition != std::string::npos) {
        return filename.substr(0, dotPosition) + newExt;
    }
    return filename + newExt;
}

int main(int argc, char* argv[]) {
    if (argc < 3) {
        std::cout << "Usage: " << argv[0] << " <dir name> <number of spins>" << std::endl;
        return 1;
    }
    if (argc == 4) {
        debug = true;
    }

    const char* inputDirectory = argv[1];
    int spins = std::atoi(argv[2]);

    size_t dirNameLen = strlen(inputDirectory);
    size_t extLen = strlen(EXTENSION);
    size_t outputFileNameLen = dirNameLen + extLen + 1;
    char* outputFilename = new char[outputFileNameLen];
    strcpy_s(outputFilename, outputFileNameLen, inputDirectory);
    strcat_s(outputFilename, outputFileNameLen, EXTENSION);

    compressFile(inputDirectory, outputFilename, spins);

    delete[] outputFilename;
    return 0;
}

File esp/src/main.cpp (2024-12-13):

#define FASTLED_ALL_PINS_HARDWARE_SPI
#define FASTLED_ESP32_SPI_BUS FSPI
#include <SPI.h>
#include <Arduino.h>
#include <WiFiClientSecure.h>
#include <FastLED.h>
#include <ESPmDNS.h>
#include "Debug.h"
#include "Wireless.h"
#include "LedArray.h"
#include "AnimDB.h"
#include "FS.h"
#include "SPIFFS.h"
#include "State.h"
#include "WebSocket.h"

#define MDNS_NAME "upper_esp"

WiFiClientSecure *wifiClient;
Wireless *wireless;
WebSocketServer *webSocketServer;
LedArray *ledArray;
AnimDB *animDB;

uint32_t maxTime = 0;
uint32_t lastMicros = micros();

CRGB *leds_fb_test;
CRGB *leds_bb_test;

State previousState = State::INIT;
State currentState = State::INIT;
State nextState = State::NONE;

TaskHandle_t* webSocketHandle = NULL;

void webSocketLoop(void *parameter)
{
    Debug::info("Websocket loop started...");
    while (true)
    {
        webSocketServer->loop();
        vTaskDelay(10 / portTICK_PERIOD_MS);
    }
}

void webSocketTask(){
    if (!MDNS.begin(MDNS_NAME)) {
        Serial.println("mDNS setup error");
        currentState = State::ERROR;
    }
    else{
        Debug::raw("MDNS: " + String(MDNS_NAME));
    }
    webSocketServer = new WebSocketServer();
    webSocketServer->begin();
    xTaskCreatePinnedToCore(
        webSocketLoop,
        "webSocketLoop",
        4096,
        NULL,
        2,
        webSocketHandle,
        0
    );
}

void resetNextState(){
    nextState = State::NONE;
}

void setup()
{
    Debug::init();
    Debug::info("Starting...");
    
    wifiClient = new WiFiClientSecure();
    wireless = new Wireless();

    animDB = new AnimDB();
    animDB->print();
}

int avgTime = 0;
int count = 0;
uint32_t maxTimeX = 0;
uint32_t debugTime = 0;
uint32_t timeX;

void loop()
{
    switch (currentState)
    {
        case INIT:
        { 
            Debug::info("Initializing...");
            
            if (wireless->isConnected()) {
                Debug::info("WiFi already connected. Switching to READY state.");
                currentState = State::READY;
            } else {
                Debug::info("WiFi not connected. Switching to CONNECT_WIFI state.");
                currentState = State::CONNECT_WIFI;
            }
            break;
        }

        case CONNECT_WIFI:
        {
            Debug::info("Trying to connect to WiFi...");
            
            wireless->connectToNetwork();
            
            if (wireless->isConnected()) {
                Debug::info("Successfully connected to WiFi. Switching to READY state.");
                webSocketTask();
                currentState = State::READY;
            } else {
                Debug::info("WiFi connection failed. Switching to SETUP_WIFI state.");
                currentState = State::SETUP_WIFI;
            }
            break;
        }

        case SETUP_WIFI:
        {
            Debug::info("Setting up Access Point (AP)...");
            
            if(!wireless->runningAP())
                wireless->startAP();

            if (wireless->isConnected()) {
                Debug::info("Successfully connected to WiFi after AP setup. Switching to READY state.");
                wireless->stopAP();
                esp_restart();
            } else {
                Debug::info("Waiting for WiFi credentials from AP.");
            }
            break;
        }

        case READY:
        {
            
            if (nextState == State::ANIMATION) {
                Debug::info("LED animation ready to display. Switching to ANIMATION state.");
                currentState = State::ANIMATION;
                resetNextState();
            }
            break;
        }

        case ANIMATION:
        {
            if (ledArray != NULL && ledArray->isReady()) {
                ledArray->nextFrame();

                uint32_t currentTime = micros();
                uint32_t frameTime = currentTime - lastMicros;
                lastMicros = currentTime;

                count++;
                avgTime += frameTime;
                if (maxTimeX < frameTime) maxTimeX = frameTime;

                if (count == 1000) {
                    Debug::info("Average time: " + String(avgTime / count) + " Max time: " + String(maxTimeX));
                    avgTime = 0;
                    count = 0;
                    maxTimeX = 0;
                }
            }
            if (nextState == STOP_ANIMATION){
                currentState = State::STOP_ANIMATION;
                resetNextState();
            }
            break;
        }

        case STOP_ANIMATION:
        {
            Debug::info("Stopping the animation.");
            if(ledArray!=NULL){
                delete ledArray;
                ledArray = NULL;
            }
            currentState = State::READY;
            break;
        }

        case ERROR:
        {
            Debug::error("An error occurred. Restarting WiFi setup...");
            wireless->clearCredentials();
            currentState = State::CONNECT_WIFI;
            break;
        }
    }
    if (currentState == previousState && currentState != ANIMATION) {
        vTaskDelay(1000 / portTICK_PERIOD_MS);
    }
    previousState = currentState;
}

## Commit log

2024-07-14 chore: Add Blender files
    [cube.blend]
2024-07-15 chore: Refactor Wireless class, remove goto
2024-07-15 feat: Add connectToNetwork method to Wireless class
2024-07-15 chore: Update Wireless class to handle new network credentials
2024-07-15 Refactor Wireless class, remove goto
2024-07-15 chore: Add MQTT test functionality for subscribing to "esp32/ledarray"
2024-07-15 chore: Update platformio.ini with new dependencies and monitor filters
2024-07-17 chore: Update MQTT publish topic to "esp32/alive_status"
2024-07-18 chore: Update MQTT subscribe topic to "esp32/check_alive" and publish "esp32/alive_status"
2024-07-18 feat: Add ESP32 WiFi configuration option to PreConnectionRouter
2024-07-18 feat: Add HttpEspController for handling ESP32 HTTP requests
2024-08-14 refactor: Update FastLED library version to 3.7.1 and add LED array functionality
2024-08-14 frames added to mqtt messages
2024-08-15 LedArray callback function on buffer swap
    [LedArray.h, main.cpp]
2024-08-16 refactor: Update LED array buffer size and animation frames
2024-08-18 fixed compiling, added actions for github
    [LedArray.h, main.cpp]
2024-08-19 + added BUS to templates for SPI lanes
2024-08-19 refactor: Remove unused LED controller types from FastLED.h
2024-08-19 refactor: Update LED array controller initialization with BUS parameter
2024-08-19 refactor: Update LED array initialization with green color
2024-08-19 refactor: Update LED array initialization and animation frames
2024-08-19 feat: Modify SPI library for esp32
2024-08-19 refactor: Clear LedArray from unused code
2024-08-19 +feat added second pcb design
    [inz.kicad_pcb, inz.kicad_sch]
2024-08-19 +feat: added footprints
2024-08-19 big messages not working (before changing pubsubclient)
    [LedArray.h]
2024-08-19 Fixed Led alignment in the pcb project
    [inz.kicad_pcb]
2024-08-20 pcb update
    [inz.kicad_pcb, inz.kicad_sch]
2024-08-22 Added led connections on pcb
    [inz.kicad_pcb, inz.kicad_sch]
2024-08-22 Connected led columns together
    [inz.kicad_pcb]
2024-08-26 +feat: finished second pcb design
    [inz-B_Cu.gbr, inz-B_Mask.gbr, inz-B_Paste.gbr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]
2024-08-27 refactor: Remove unused code in Wireless.h
2024-08-27 feat: Add partitions.csv and update platformio.ini
    [partitions.csv]
2024-08-28 added 3d models
    [kat 2 v1.f3d, silnik góra v2.f3d, silnik v1 v2.f3d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]
2024-08-29 animDB bugfix + animDB test python script
    [main.cpp]
2024-08-29 chore: Add Colors.h for managing LED colors
2024-08-30 refactor: Add Decompressor class for managing LED color decompression
2024-08-30 refactor: Remove Colors.h and update LedArray class to use Decompressor for managing LED color decompression
2024-09-23 refactor: Remove constant data from Wireless.h
2024-09-23 feat: new models
    [dysk v3.f3d, podstawa v2.f3d, silnik góra v3.f3d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]
2024-09-24 feat: Add animationNames FrameType handling
2024-09-24 fix: Load colors from buffer
    [Decompressor.h]
2024-09-25 fix: Wrong output size
    [Decompressor.h]
2024-09-25 feat: Added blend file for atom animation
    [atom.blend]
2024-09-25 fix: Updated rendering script
    [atom.blend]
2024-09-25 fix: Removed setting doneProcessing in wrong place
    [LedArray.h]
2024-09-26 fix: Compressor now rotates frames
    [ledarray_compressor.cpp]
2024-09-26 fix: Fixed compressor's rotate function.
    [ledarray_compressor.cpp]
2024-10-06 refactor: Wireless class update
2024-10-06 fix: Animation stop frame handle
2024-11-28 refactor: Basic frame types handling
2024-11-29 refactor: Most frame types handling
2024-11-29 fix: Proper buffor size
    [LedArray.h, WebSocket.h]
2024-11-29 fix: Wrong buffer swap
    [Decompressor.h, LedArray.h]
